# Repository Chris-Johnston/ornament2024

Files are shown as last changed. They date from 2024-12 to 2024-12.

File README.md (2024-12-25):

# Xmas Ornament 2024

Another ATTiny404-based LED Xmas tree ornament.

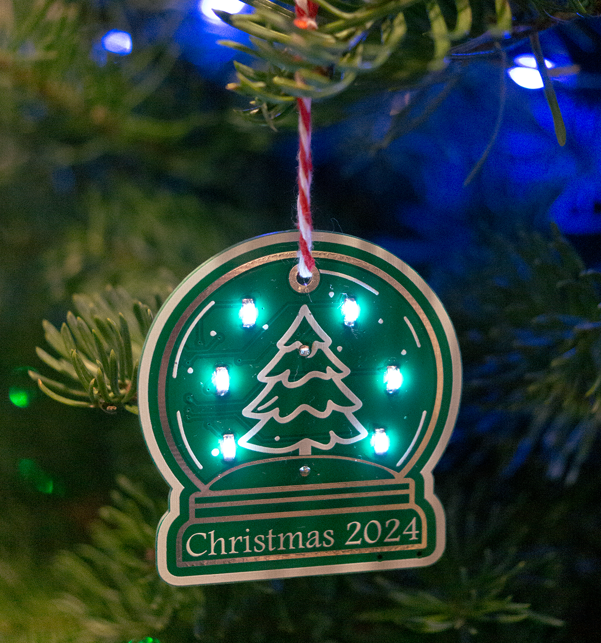
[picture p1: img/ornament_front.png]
image of the ornament hanging from a tree


This is a continuation of a series of these boards that I've worked on in [2023], [2022], and [2021].

[2023]: https://github.com/Chris-Johnston/ornament2023/
[2022]: https://github.com/Chris-johnston/ornament2022
[2021]: https://github.com/Chris-Johnston/snowflake-ornament

This year's iteration was pretty similar to [2023]'s wreath-shaped ornament. Some new things I tried this year were:

- Another new design, largely adapted from a stock image library
- Using negative solder mask (solder mask mask?) to include exposed pads for aesthetic effect
- Simplified the design and opted for single color LEDs, instead of the bi-color ones from the last 2 years

Of these, the new design came out well and the exposed pads look nice. I used these on another board this year and I think I'll continue to do so in the future.

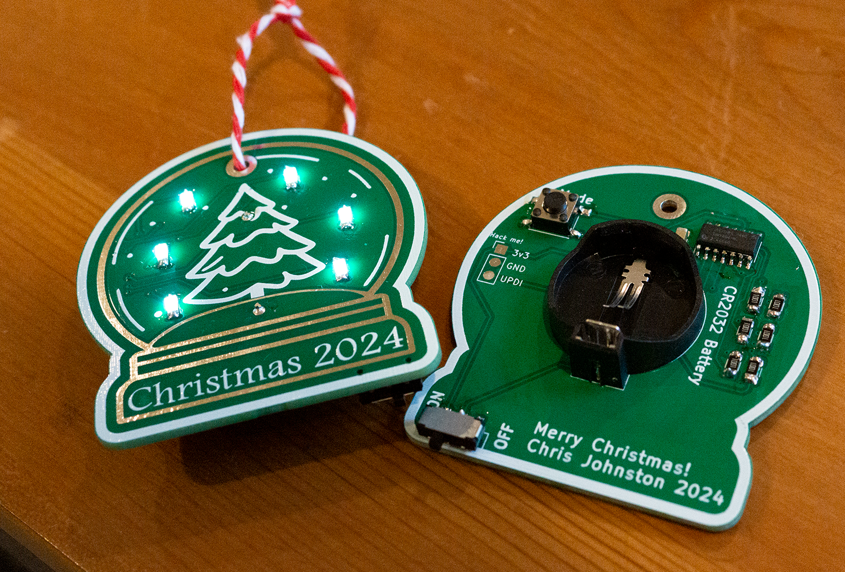
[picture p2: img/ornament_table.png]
image of the ornaments sitting on a table


# Timeline

Last year I said I was in a time crunch, but this year I waited even longer to start, and had plenty of other things going on.

| Date | |
| - | - |
| TODO | Started working on the first design revision |
| TODO | Scrapped first design revision to work on another |
| November 23 2024 | Ordered parts. |
| December 1 2024 | Ordered circuitboards. |
| December 2 2024 | Parts arrive. |
| December 12 2024 | Circuitboards arrive. | 
| December 14 2024 | Put the first one together, LEDS are way too bright. |
| December 20 2024 | Replaced resistors to address LED brightness problem. |
| December 21 2024 | Assembled 15 boards |
| December 23 2024 | Still working on the code |

# Resources

- [svg2mod](https://github.com/svg2mod/svg2mod) was used to generate the footprint of the board, silkscreen layers, and negative soldermask.
  - I used another vector editor to create the designs, exported these to Inkscape, and then used `svg2mod` to create the footprints.

I was able to reuse [my UPDI board for programming these boards from 2 years ago](https://github.com/Chris-johnston/ornament2022?tab=readme-ov-file#changes-from-last-years-version).

# Bill of Materials

| Reference | Description | Part No. | Price |
| -- | -- | -- | -- |
| PCB | Made via fabricator in China. | | Absurdly cheap |
| C1 | 1 uf 1206 capacitor | CL31B105KAHNNNE | $0.0534 |
| D1-D6 | 1206 White LED | TODO | |
| R1-R6 | 1206 1K Resistor | Generic | |
| SW1 | 6x6mm Pushbutton | Generic | |
| SW2 | Slide Switch | JS102011SAQN | |
| U1 | ATTiny404 | Attiny404 | | 
| B1 | CR2023 Battery Holder | BH-25C-1 | |

Unit cost without shipping: **TODO**

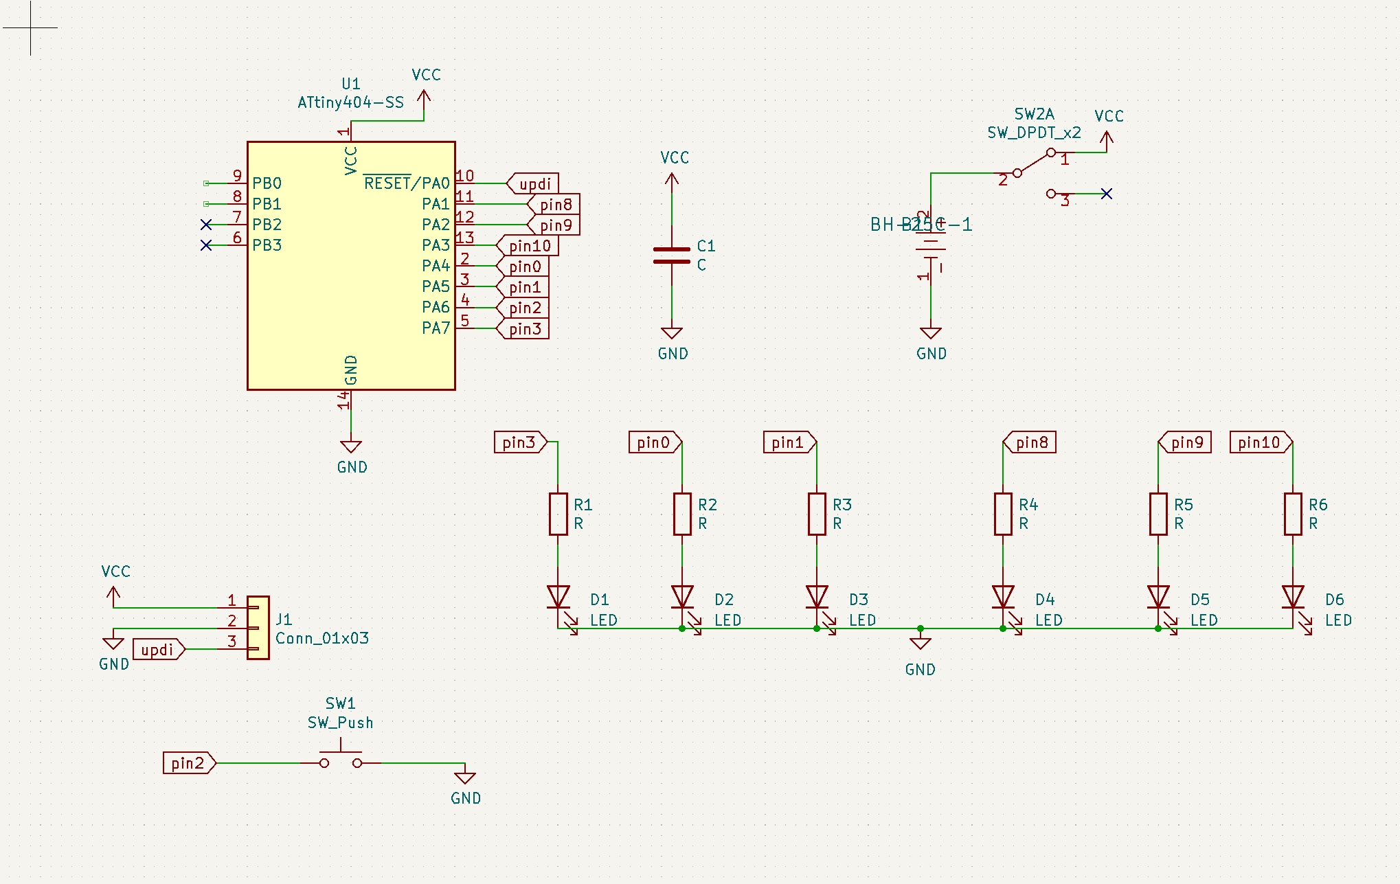
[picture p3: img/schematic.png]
schematic screenshot in case I'm too lazy to open up kicad


# Oops

In redoing the circuit this year (since I only wanted to use single color LEDs), I thought it would be simpler to only use Digital I/O pins on PORTA of the ATTiny404. I also misread the ATTiny404 manual and thought that each of these pins had PWM. This wasn't correct, these pins had a ADC but not PWM outputs.

To add to the problem, the LEDs I had picked out this time around were _absurdly_ bright. This could be a skill issue, but I found it hard to find in-stock and cheap surface-mount white LEDs which were bright enough to *indicate* but not *illuminate*. As a result, the ones I ordered were some high number of lumens in output. This year was a time crunch, and so I ordered the resistors I thought I had needed with the LEDs without testing them.

This meant that I was stuck with white LEDs which were way too bright, on pins that didn't built-in PWM.

To fix this I ended up implementing a software PWM implementation. It relies on one of the ATTiny404's timer interrupts, which updates a timer, and then updates the state each of the LED's I/O. This seems to work fine so long as the timer interrupt consistently fires.

In setting up the ISR, I unintentionally messed with the timer used to track runtime, used by `millis()`. Dividing this value by 8 first solves the problem to the extent that I care to fix it.

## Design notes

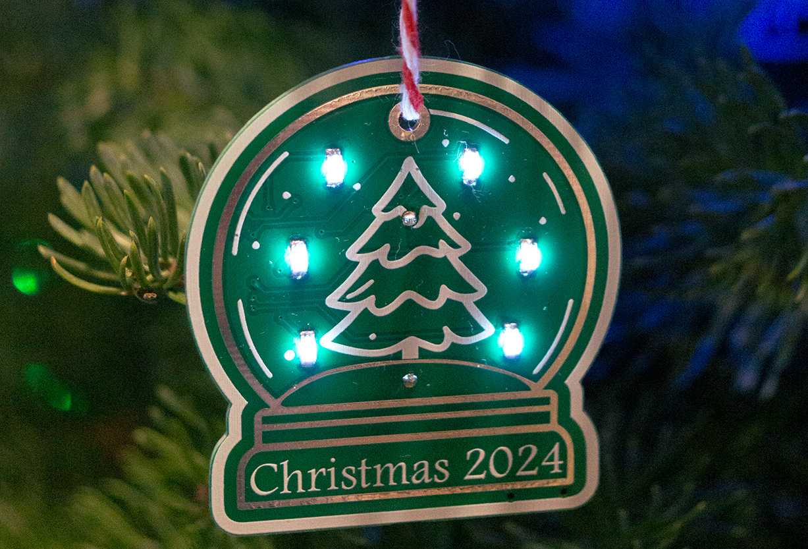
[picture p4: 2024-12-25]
img/thumbnail.jpg

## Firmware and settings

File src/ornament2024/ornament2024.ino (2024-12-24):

// ornament 2024 code

// This code is messy - I do not care. You have been warned.

#include <avr/io.h>
#include <avr/interrupt.h>
#include <util/delay.h>
#include <avr/pgmspace.h>
#include <pins_arduino.h>
#include "ornament.h"

#define PIN_OUTPUT_COUNT 6
#define PIN_BUTTON 2

#undef MILLIS_USE_TIMERB0

#define DEBOUNCE_TIME 75

// Clockwise starting from the top
int pins[] = {
  3, 0, 1, 10, 9, 8
};

// I broke the millis() timer when setting up the ISR
// and I do not care enough to fix it.
// This is fine.
// nevermind I wasn't using TIMERA0 anyways so reverted this change

#define CORRECTED_MILLIS (millis())
#define CORRECTED_DELAY(ms) (delay(ms))

// 8       3
// 9 tree  0
// 10      1

unsigned long lastDebounceTime = 0;
int pattern = 0;

void setupIsr();
void clear();

void setup() {
  
  for (int i = 0; i < PIN_OUTPUT_COUNT; i++)
  {
    pinMode(pins[i], OUTPUT);
  }
  pinMode(PIN_BUTTON, INPUT_PULLUP);

  setupIsr();

  // TODO: look into using the VREF features so that I can see how drained the battery is
}

int lastButtonState = 0;
int buttonState = 0;

// state used for software PWM
uint8_t pwmTimers[PIN_OUTPUT_COUNT];
bool pwmTimersEnabled[PIN_OUTPUT_COUNT];
int pwmTimer = 0;

void setPwm(int pin, bool pwmEnabled, int pwmRate)
{
  pwmTimersEnabled[pin] = pwmEnabled;
  if (pwmEnabled)
  {
    pwmTimers[pin] = pwmRate & 255;
  }
  else {
    pwmTimers[pin] = 0;
  }
}

ISR(TCB0_INT_vect) {

  pwmTimer = (pwmTimer + 1) % 255;
  uint8_t portASet = 0, portAClear = 0;
  
  for (int i = 0; i < PIN_OUTPUT_COUNT; i++) {
    // preserve whatevers already in the register
    if (pwmTimersEnabled[i] == false) continue;
    
    if (pwmTimer < pwmTimers[i]) {
      portASet |= digital_pin_to_bit_mask[pins[i]];
    }
    else {
      portAClear |= digital_pin_to_bit_mask[pins[i]];
    }
  }

  PORTA.OUTSET = portASet;
  PORTA.OUTCLR = portAClear;

  TCB0.INTFLAGS = 0; // clear interrupt
}

ISR(PORTA_PORT_vect) {
  byte flags = PORTA.INTFLAGS;
  PORTA.INTFLAGS |= flags;
  
  if ((CORRECTED_MILLIS - lastDebounceTime) > DEBOUNCE_TIME) {

    pattern = (pattern + 1) % NUM_PATTERNS;
    clear();

    lastDebounceTime = CORRECTED_MILLIS;
  }
}

#define TCB0_CTRLA_ENABLE 1
#define TCB0_CTRLA_CLKSEL_1 0 // CLK_PER
#define TCB0_CTRLA_CLKSEL_half 1 // CLK_PER / 2
#define TCB0_CTRLB_ASYNC 0b01000000
#define TCB0_CTRLB_PERIODIC_INTERRUPT_MODE 0b00

void setupIsr() {
  TCB0.CCMP = 0xfff;
  TCB0.CTRLB = TCB0_CTRLB_ASYNC | TCB0_CTRLB_PERIODIC_INTERRUPT_MODE;
  TCB0.INTCTRL = 1 ; // no capture interrupt
  TCB0.CTRLA = TCB0_CTRLA_CLKSEL_half | TCB0_CTRLA_ENABLE;
  
  // pin 2 interrupt
  // bit 7 invert I/O
  // pull up enabled (bit 3)
  // bits 2:0 - sense falling edge
  // PORTA_PIN2CTRL = 0b1000 | 0x3;

  // pin 2 is actually pa6
  PORTA.INTFLAGS = (1 << 6);// 0b100;
  PORTA.PIN6CTRL = 0b10000000 | 0b1000 | 0b11;
  VPORTA.INTFLAGS = (1 << 6);
  // PORTA.INTCTRL = 1;
  // PORTA.PIN2CTRL = 0b1011;
}

// this was necessary when I didn't use the right value of resistor
// but has been fixed now, should be fine to use the full range of resistor
// without burning anyone's eyes
// additionally this prevents LEDs being on way too bright if the board browns out or
// gets stuck.

// anything beyond this is too dang bright
// #define MAX_PWM_BRIGHTNESS 50

void showPattern()
{
  (*patternList[pattern])();
}

void loop()
{
  showPattern();
  delay(50); // don't need to spin super fast
}

void clearPwm() {
  for (int i = 0; i < PIN_OUTPUT_COUNT; i++) {
    setPwm(i, false, 0);
  }
}

void clear()
{
  clearPwm();
  PORTA.OUT = 0;
}

void offPattern()
{
  // nothing - no point in doing this
}

void randomBlinkPattern() {
  clear();
  delay(125 + rand() % 500);
  setPwm(rand() % PIN_OUTPUT_COUNT, true, rand() % 255);
  delay(50);
}

void defaultPattern() {
  for (int i = 0; i < PIN_OUTPUT_COUNT; i++) {
    setPwm(i, true, (i % 2 == 1) ? 255 : 128);
  }
}

void spinPattern() {
  // pretty sure these are getting stuck ons
  clearPwm();
  int on = (CORRECTED_MILLIS / 300) % PIN_OUTPUT_COUNT;
  int bit = digital_pin_to_bit_mask[pins[on]];
  PORTA.OUT = bit;
}

void spinReversePattern() {
  // pretty sure these are getting stuck ons
  clearPwm();
  int on = (CORRECTED_MILLIS / 300) % PIN_OUTPUT_COUNT;
  int bit = digital_pin_to_bit_mask[pins[(PIN_OUTPUT_COUNT - 1) - on]];
  PORTA.OUT = bit;
}

void sineSpinPattern() {
  for (int i = 0; i < PIN_OUTPUT_COUNT; i++) {
    setPwm(i, true, (255/2) + (100.0) * sin( 6.28 * (i / 8.0) + (CORRECTED_MILLIS / 2500.0)));
  }
  delay(50);
}

// sin was too slow
int vSpinPatternLUT[] = {0, 50, 255, 128, 50, 0 };

void vSpinPattern() {
  int offset = (int)(CORRECTED_MILLIS / 100.0) % PIN_OUTPUT_COUNT;

  for (int i = 0; i < PIN_OUTPUT_COUNT; i++) {
    setPwm(i, true, vSpinPatternLUT[(i + offset) % PIN_OUTPUT_COUNT]);
  }
}

void clockPattern() {
  clearPwm();
  int time = ((int)(CORRECTED_MILLIS / 1000.0)) & 0b111111;
  int portaValue = 0;

  for (int i = 0; i < PIN_OUTPUT_COUNT; i++) {
    portaValue |= (time & 1) * digital_pin_to_bit_mask[pins[i]];
    time = time >> 1;
  }

  PORTA.OUT = portaValue;
}

void solidFullBrightnessPattern() {
  clearPwm();
  int portaValue = 0;
  for (int i = 0; i < PIN_OUTPUT_COUNT; i++) {
    portaValue |= digital_pin_to_bit_mask[pins[i]];
  }
  PORTA.OUT = portaValue;
}

void halfBrightnessPattern() {
  for (int i = 0; i < PIN_OUTPUT_COUNT; i++) {
    setPwm(i, true, 255/2);
  }
}

void quarterBrightnessPattern() {
  for (int i = 0; i < PIN_OUTPUT_COUNT; i++) {
    setPwm(i, true, 255/4);
  }
}



// turns an LED on and decays it over time
unsigned long lastBlinkPatternTime = 0;
void decayPattern() {

  int period = 500 + rand() % 500;

  if (lastBlinkPatternTime == 0 || ((CORRECTED_MILLIS - lastBlinkPatternTime) > period)) {
    lastBlinkPatternTime = CORRECTED_MILLIS;

    int r = rand() % PIN_OUTPUT_COUNT;
    setPwm(r, true, 255);
  }

  for (int i = 0; i < PIN_OUTPUT_COUNT; i++) {
    if (pwmTimers[i] > 0) {
      pwmTimers[i] *= 0.9;
    }
  }
}

int snowPatternCounter = 0;

// actually doesn't need to refer to the pin number
// 8  3
// 9  0
// 10 1
// since setPwm will look this up
// so instead should refer to the clockwise order

// 5  0
// 4  1
// 3  2
//

int snowPatternSequence[] = {
  0, 1, 2,
  5, 4, 3,
  0, 5, 1, 4, 2, 3,
  5, 4, 3,
  5, 0, 4, 1, 3, 2,
  0, 1, 2,
  0, 5, 1, 4, 2, 3,
};
#define LEN_SNOW_SEQUENCE (sizeof(snowPatternSequence) / sizeof(int))

void snowPattern() {

  int period = 200 + rand() % 400;

  if (lastBlinkPatternTime == 0 || ((CORRECTED_MILLIS - lastBlinkPatternTime) > period)) {
    lastBlinkPatternTime = CORRECTED_MILLIS;

    // int r = rand() % PIN_OUTPUT_COUNT;
    // setPwm(r, true, 255);
    snowPatternCounter = (snowPatternCounter + 1) % LEN_SNOW_SEQUENCE;
    setPwm(snowPatternSequence[snowPatternCounter], true, 255);
  }

  for (int i = 0; i < PIN_OUTPUT_COUNT; i++) {
    if (pwmTimers[i] > 0) {
      pwmTimers[i] *= 0.7;
    }
  }
}

void debugPattern() {
  bool state = (CORRECTED_MILLIS / 1000) % 2;
  digitalWrite(pins[0], state);
}

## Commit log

2024-12-24 upload pcb design files
    [ornament2024.kicad_pcb, ornament2024.kicad_sch]
2024-12-24 got pin interrupt working, fixed timer A
    [ornament2024.ino]
